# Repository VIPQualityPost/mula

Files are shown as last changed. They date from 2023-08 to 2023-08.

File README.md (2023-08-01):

A small 16ch 100MHz logic analyzer with 2-5V protected inputs that is 
compliant with SUMP/OLS and is usable in sigrok. It is based on 
the rp2040 rust logic analyzer firmware 
[`ula`](https://github.com/dotcypress/ula.git) written by 
[@dotcypress](https://github.com/dotcypress). The 
small form factor is designed for a socket to be designed into a circuit board 
using cheap and widely available m.2 sockets, or by using some custom 
carriers which allow you to use popular flying probes, like the ones 
provided with bitmagic or the classic HP 01652-61608.

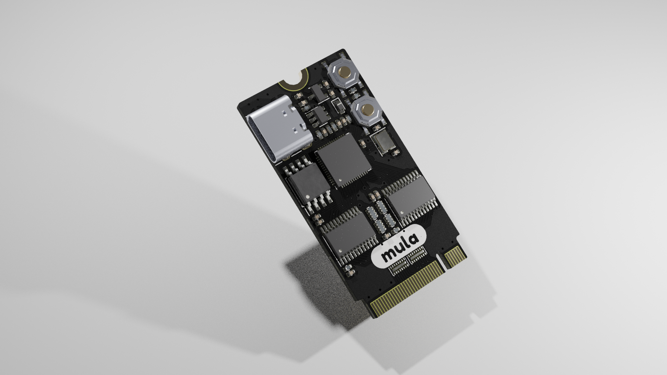
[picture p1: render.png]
3D render of PCB


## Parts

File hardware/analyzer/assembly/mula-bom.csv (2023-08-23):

Comment | Designator | Footprint | JLCPCB Part #
10k | R109,R107,R108,R106 | 0402_R
LED | D101 | 0603_D | C2290
IP4252CZ16-8-TTL,1 | L102,L101 | UDFN-16 | C458218
W25Q128JVS | U101 | SOIC-8 | C97521
12MHz | Y101 | Crystal_SMD_3225 | C9002
SN74LVC4245 | U106,U105 | TSSOP-24 | C7859
XC6206 | U104 | SOT-23 | C5446
SRV05-4 | U103 | SOT-23-6 | C85364
RP2040 | U102 | QFN-56 | C2040
BUTTON | SW101, SW102 | TS-1187A-B-A-B | C318884
150k | RN104,RN103,RN102,RN101 | R_Array_Concave_4x0402 | C425271
27R | R105,R104 | 0402_R
5k1 | R103,R102 | 0402_R
1k | R101 | 0402_R
USB_C_Receptacle_USB2.0 | J101 | HRO_TYPE-C-31-M-12 | C165948
100n | C116,C115,C112,C111,C109,C107,C106,C105 | 0402_C
4u7 | C114,C108 | 0402_C
1u | C113,C110 | 0402_C
47p | C104,C103 | 0402_C
20p | C102,C101 | 0402_C

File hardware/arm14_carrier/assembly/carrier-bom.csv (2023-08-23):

Comment | Designator | Footprint | LCSC Part #
BANKS | J101, J102 | HDR-SMD_14P-P1.27-V-M-R2-C7-LS5.3 | C3975190
NASB0-S6701-TPH4 | CN101 | CONN-SMD_NXSB0-S67XX-XXH4 | C367024

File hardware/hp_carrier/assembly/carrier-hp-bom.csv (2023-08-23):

Comment | Designator | Footprint | LCSC Part #
NASB0-S6701-TPH4 | CN101 | CONN-SMD_NXSB0-S67XX-XXH4 | C367024

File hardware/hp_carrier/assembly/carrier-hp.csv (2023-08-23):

Id | Designator | Footprint | Quantity | Designation | Supplier and ref
1 | J101 | IDC-Header_2x20_P2.54mm_Horizontal | 1 | HP_PROBE
2 | H101,H104,H102,H103 | MountingHole_3mm_Pad | 4 | M3
3 | CN101 | CONN-SMD_NXSB0-S67XX-XXH4 | 1 | NASB0-S6701-TPH4
4 | H105 | MountingHole_2.2mm_M2_DIN965_Pad | 1 | M2

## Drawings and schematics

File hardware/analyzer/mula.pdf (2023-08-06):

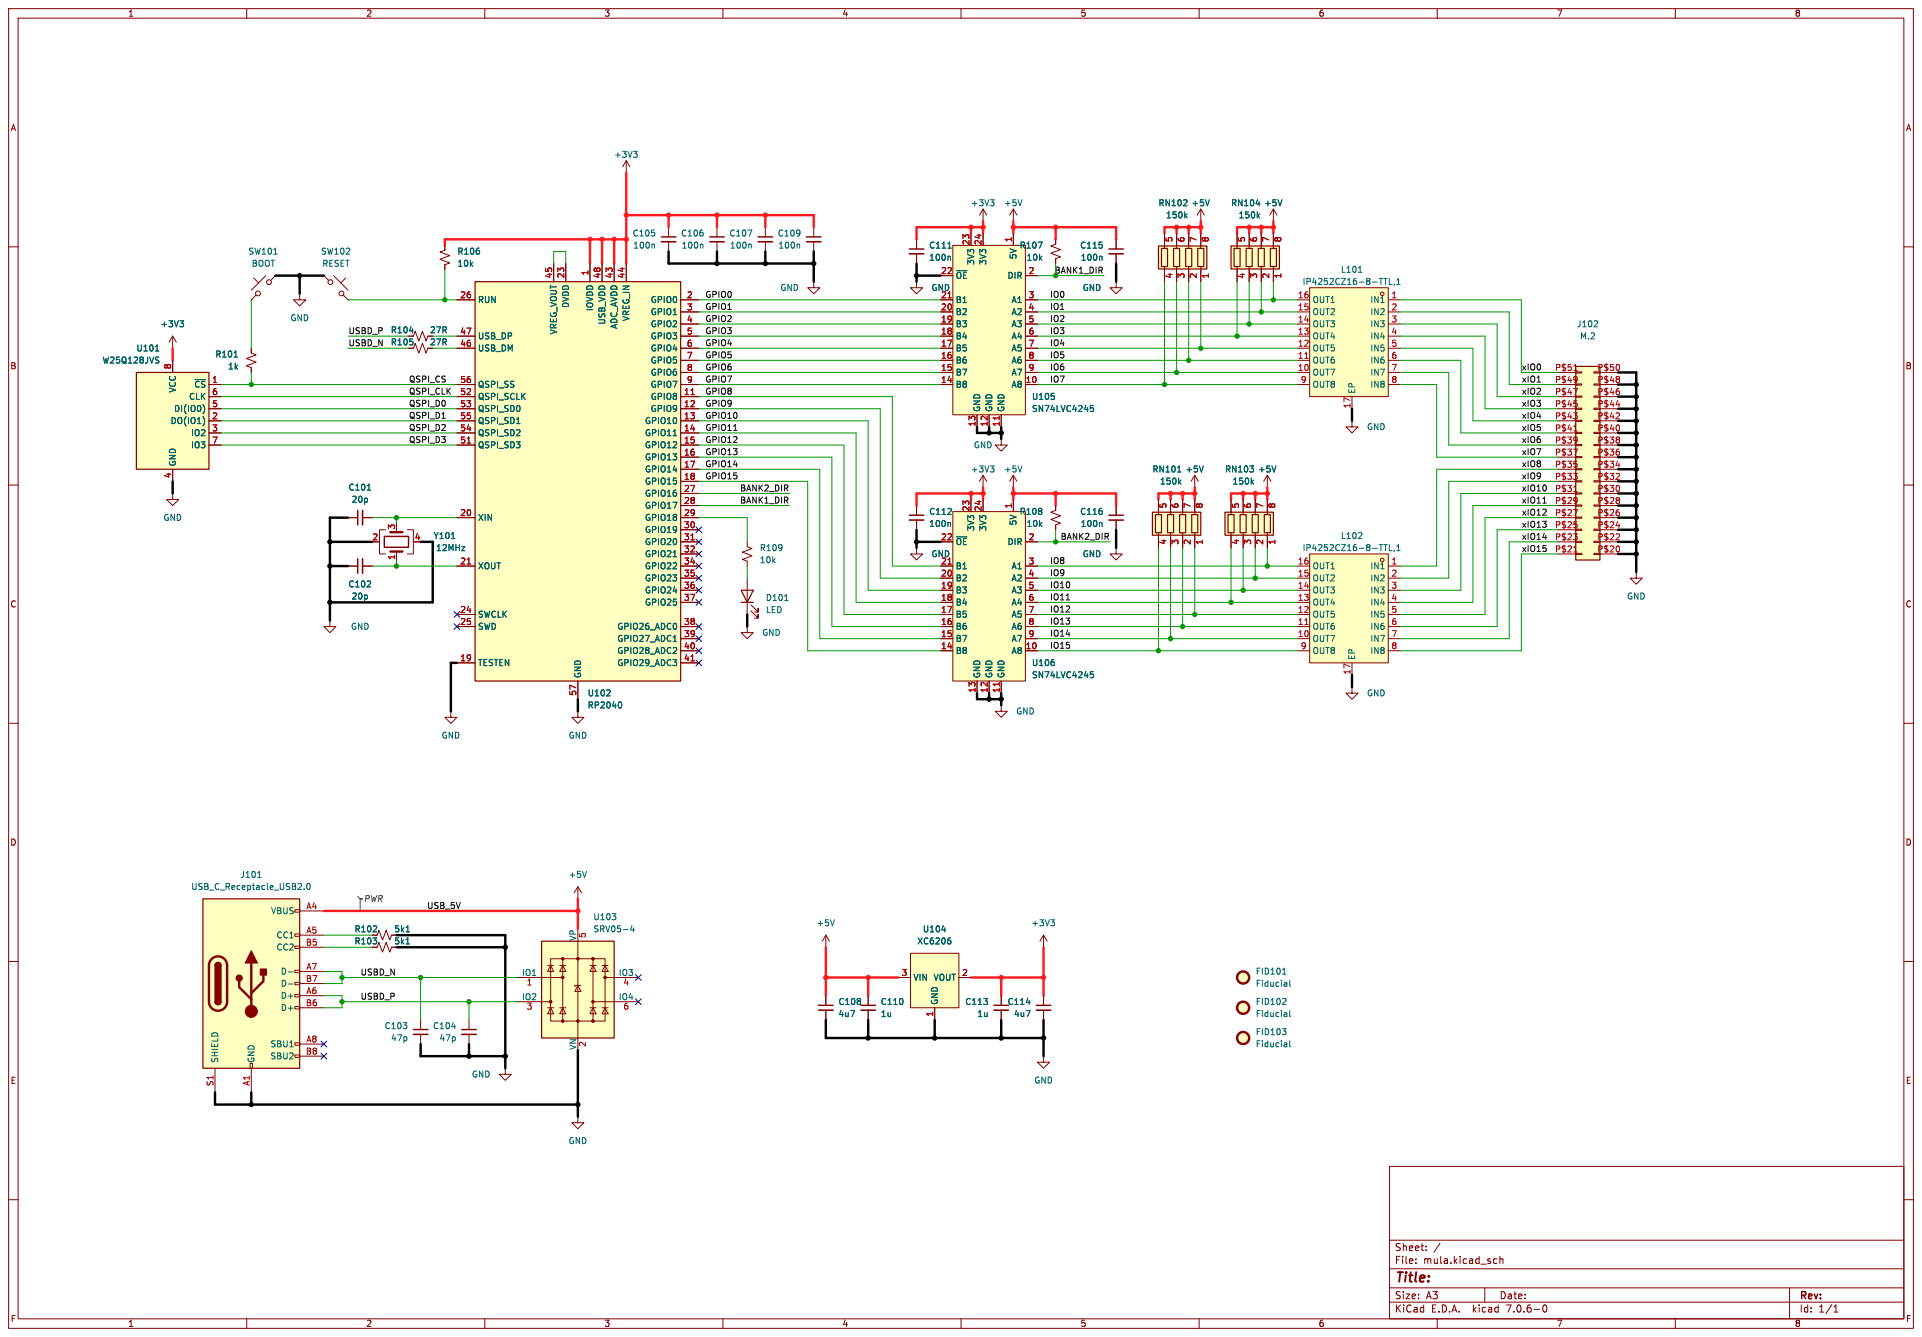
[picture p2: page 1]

1 GPIO8 11 GPIO9 12 GPIO10 13 GPIO11 14 GPIO12 15 GPIO13 16 GPIO14 17 GPIO15 18 TESTEN 19 GPIO0 2 XIN 20 XOUT 21 DVDD 23 SWCLK 24 SWD 25 RUN 26 GPIO16 27 GPIO17 28 GPIO18 29 GPIO1 3 GPIO19 30 GPIO20 31 GPIO21 32 GPIO22 34 GPIO23 35 GPIO24 36 GPIO25 37 GPIO26_ADC0 38 GPIO27_ADC1 39 GPIO2 4 GPIO28_ADC2 40 GPIO29_ADC3 41 ADC_AVDD 43 VREG_IN 44 VREG_VOUT 45 USB_DM 46 USB_DP 47 USB_VDD 48 GPIO3 5 QSPI_SD3 51 QSPI_SCLK 52 QSPI_SD0 53 QSPI_SD2 54 QSPI_SD1 55 QSPI_SS 56 GND 57 GPIO4 6 GPIO5 7 GPIO6 8 GPIO7 9 U102 RP2040 C101

1 GPIO8 11 GPIO9 12 GPIO10 13 GPIO11 14 GPIO12 15 GPIO13 16 GPIO14 17 GPIO15 18 TESTEN 19 GPIO0 2 XIN 20 XOUT 21 DVDD 23 SWCLK 24 SWD 25 RUN 26 GPIO16 27 GPIO17 28 GPIO18 29 GPIO1 3 GPIO19 30 GPIO20 31 GPIO21 32 GPIO22 34 GPIO23 35 GPIO24 36 GPIO25 37 GPIO26_ADC0 38 GPIO27_ADC1 39 GPIO2 4 GPIO28_ADC2 40 GPIO29_ADC3 41 ADC_AVDD 43 VREG_IN 44 VREG_VOUT 45 USB_DM 46 USB_DP 47 USB_VDD 48 GPIO3 5 QSPI_SD3 51 QSPI_SCLK 52 QSPI_SD0 53 QSPI_SD2 54 QSPI_SD1 55 QSPI_SS 56 GND 57 GPIO4 6 GPIO5 7 GPIO6 8 GPIO7 9 Y101

Id: 1/1 Title: File: mula.kicad_sch Sheet: / GND

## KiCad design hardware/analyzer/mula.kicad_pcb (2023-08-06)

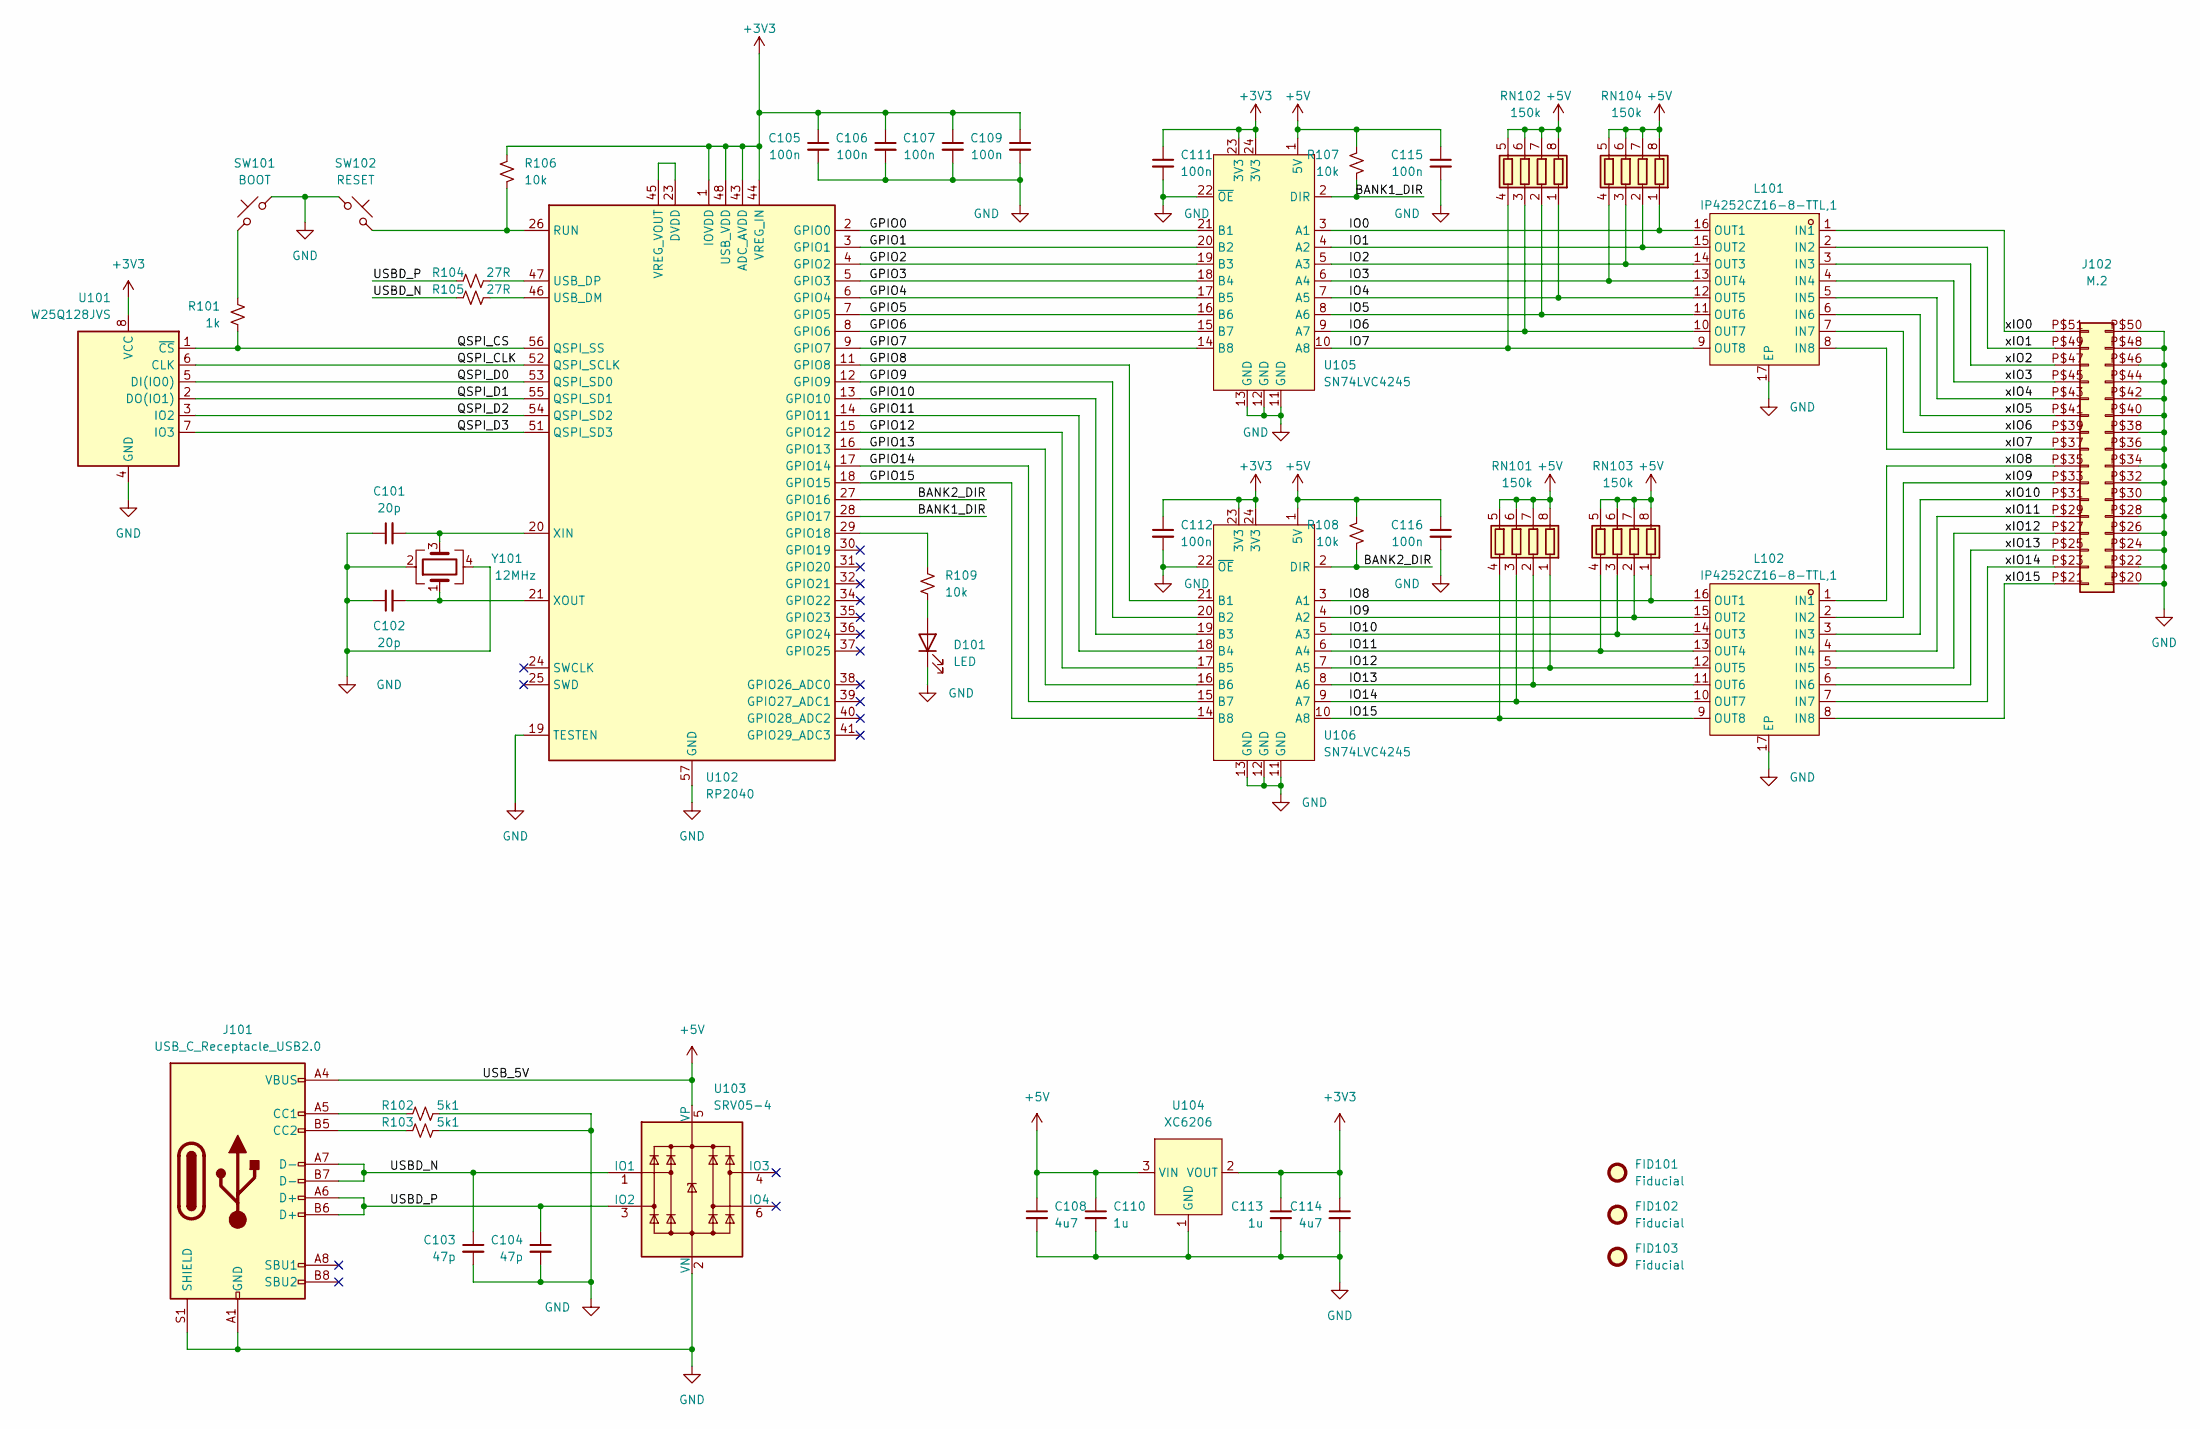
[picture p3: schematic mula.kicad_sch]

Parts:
C101, C102: 20p; C_0402_1005Metric
C103, C104: 47p; C_0402_1005Metric
C105, C106, C107, C109, C111, C112, C115, C116: 100n; C_0402_1005Metric
C108, C114: 4u7; C_0402_1005Metric
C110, C113: 1u; C_0402_1005Metric
D101: LED; D_0603_1608Metric
FID101, FID102, FID103: Fiducial; Fiducial_0.5mm_Mask1mm
J101: USB_C_Receptacle_USB2.0; USB_C_Receptacle_HRO_TYPE-C-31-M-12; LCSC Part C165948
J102: M.2; M.2-B-KEY
L101, L102: IP4252CZ16-8-TTL,1; UDFN-16_L3.3-W1.4-P0.40-BL-EP; LCSC Part C458218
R101: 1k; R_0402_1005Metric
R102, R103: 5k1; R_0402_1005Metric
R104, R105: 27R; R_0402_1005Metric
R106, R107, R108, R109: 10k; R_0402_1005Metric
RN101, RN102, RN103, RN104: 150k; R_Array_Concave_4x0402; LCSC Part C425271
SW101: BOOT; TS-1187A-B-A-B; LCSC Part C318884
SW102: RESET; TS-1187A-B-A-B; LCSC Part C318884
U101: W25Q128JVS; SOIC-8W_5.3x5.3mm_P1.27mm; LCSC Part C97521
U102: RP2040; QFN-56-1EP_7x7mm_P0.4mm_EP3.2x3.2mm; LCSC Part C2040
U103: SRV05-4; SOT-23-6; LCSC Part C85364
U104: XC6206; SOT-23; LCSC Part C5446
U105, U106: SN74LVC4245; TSSOP-24_4.4x7.8mm_P0.65mm; LCSC Part C7859
Y101: 12MHz; Crystal_SMD_3225-4Pin_3.2x2.5mm; LCSC Part C9002

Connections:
+3V3: C105.1, C106.1, C107.1, C109.1, C111.1, C112.1, C113.1, C114.1, R106.1, U101.8 (VCC), U102.1 (IOVDD), U102.10 (IOVDD), U102.22 (IOVDD), U102.33 (IOVDD), U102.42 (IOVDD), U102.43 (ADC_AVDD), U102.44 (VREG_IN), U102.48 (USB_VDD), U102.49 (IOVDD), U104.2 (VOUT), U105.23 (3V3), U105.24 (3V3), U106.23 (3V3), U106.24 (3V3)
+5V: C108.1, C110.1, C115.1, C116.1, J101.A4 (VBUS), J101.A9 (VBUS), J101.B4 (VBUS), J101.B9 (VBUS), R107.1, R108.1, RN101.5 (R4.2), RN101.6 (R3.2), RN101.7 (R2.2), RN101.8 (R1.2), RN102.5 (R4.2), RN102.6 (R3.2), RN102.7 (R2.2), RN102.8 (R1.2), RN103.5 (R4.2), RN103.6 (R3.2), RN103.7 (R2.2), RN103.8 (R1.2), RN104.5 (R4.2), RN104.6 (R3.2), RN104.7 (R2.2), RN104.8 (R1.2), U103.5 (VP), U104.3 (VIN), U105.1 (5V), U106.1 (5V)
/BANK1_DIR: R107.2, U102.28 (GPIO17), U105.2 (DIR)
/BANK2_DIR: R108.2, U102.27 (GPIO16), U106.2 (DIR)
/GPIO0: U102.2 (GPIO0), U105.21 (B1)
/GPIO1: U102.3 (GPIO1), U105.20 (B2)
/GPIO2: U102.4 (GPIO2), U105.19 (B3)
/GPIO3: U102.5 (GPIO3), U105.18 (B4)
/GPIO4: U102.6 (GPIO4), U105.17 (B5)
/GPIO5: U102.7 (GPIO5), U105.16 (B6)
/GPIO6: U102.8 (GPIO6), U105.15 (B7)
/GPIO7: U102.9 (GPIO7), U105.14 (B8)
/GPIO8: U102.11 (GPIO8), U106.21 (B1)
/GPIO9: U102.12 (GPIO9), U106.20 (B2)
/GPIO10: U102.13 (GPIO10), U106.19 (B3)
/GPIO11: U102.14 (GPIO11), U106.18 (B4)
/GPIO12: U102.15 (GPIO12), U106.17 (B5)
/GPIO13: U102.16 (GPIO13), U106.16 (B6)
/GPIO14: U102.17 (GPIO14), U106.15 (B7)
/GPIO15: U102.18 (GPIO15), U106.14 (B8)
/IO0: L101.16 (OUT1), RN104.1 (R1.1), U105.3 (A1)
/IO1: L101.15 (OUT2), RN104.2 (R2.1), U105.4 (A2)
/IO2: L101.14 (OUT3), RN104.3 (R3.1), U105.5 (A3)
/IO3: L101.13 (OUT4), RN104.4 (R4.1), U105.6 (A4)
/IO4: L101.12 (OUT5), RN102.1 (R1.1), U105.7 (A5)
/IO5: L101.11 (OUT6), RN102.2 (R2.1), U105.8 (A6)
/IO6: L101.10 (OUT7), RN102.3 (R3.1), U105.9 (A7)
/IO7: L101.9 (OUT8), RN102.4 (R4.1), U105.10 (A8)
/IO8: L102.16 (OUT1), RN103.1 (R1.1), U106.3 (A1)
/IO9: L102.15 (OUT2), RN103.2 (R2.1), U106.4 (A2)
/IO10: L102.14 (OUT3), RN103.3 (R3.1), U106.5 (A3)
/IO11: L102.13 (OUT4), RN103.4 (R4.1), U106.6 (A4)
/IO12: L102.12 (OUT5), RN101.1 (R1.1), U106.7 (A5)
/IO13: L102.11 (OUT6), RN101.2 (R2.1), U106.8 (A6)
/IO14: L102.10 (OUT7), RN101.3 (R3.1), U106.9 (A7)
/IO15: L102.9 (OUT8), RN101.4 (R4.1), U106.10 (A8)
/QSPI_CLK: U101.6 (CLK), U102.52 (QSPI_SCLK)
/QSPI_CS: R101.2, U101.1 (~CS), U102.56 (QSPI_SS)
/QSPI_D0: U101.5 (DI(IO0)), U102.53 (QSPI_SD0)
/QSPI_D1: U101.2 (DO(IO1)), U102.55 (QSPI_SD1)
/QSPI_D2: U101.3 (IO2), U102.54 (QSPI_SD2)
/QSPI_D3: U101.7 (IO3), U102.51 (QSPI_SD3)
/USBD_N: C103.1, J101.A7 (D-), J101.B7 (D-), R105.1, U103.1 (IO1)
/USBD_P: C104.1, J101.A6 (D+), J101.B6 (D+), R104.1, U103.3 (IO2)
/xIO0: J102.P$51 (Pin_32), L101.1 (IN1)
/xIO1: J102.P$49 (Pin_31), L101.2 (IN2)
/xIO2: J102.P$47 (Pin_30), L101.3 (IN3)
/xIO3: J102.P$45 (Pin_29), L101.4 (IN4)
/xIO4: J102.P$43 (Pin_28), L101.5 (IN5)
/xIO5: J102.P$41 (Pin_27), L101.6 (IN6)
/xIO6: J102.P$39 (Pin_26), L101.7 (IN7)
/xIO7: J102.P$37 (Pin_25), L101.8 (IN8)
/xIO8: J102.P$35 (Pin_24), L102.1 (IN1)
/xIO9: J102.P$33 (Pin_23), L102.2 (IN2)
/xIO10: J102.P$31 (Pin_22), L102.3 (IN3)
/xIO11: J102.P$29 (Pin_21), L102.4 (IN4)
/xIO12: J102.P$27 (Pin_20), L102.5 (IN5)
/xIO13: J102.P$25 (Pin_19), L102.6 (IN6)
/xIO14: J102.P$23 (Pin_18), L102.7 (IN7)
/xIO15: J102.P$21 (Pin_17), L102.8 (IN8)
GND: C101.1, C102.1, C103.2, C104.2, C105.2, C106.2, C107.2, C108.2, C109.2, C110.2, C111.2, C112.2, C113.2, C114.2, C115.2, C116.2, D101.1 (K), J101.A1 (GND), J101.A12 (GND), J101.B1 (GND), J101.B12 (GND), J101.S1 (SHIELD), J102.P$20 (Pin_1), J102.P$22 (Pin_2), J102.P$24 (Pin_3), J102.P$26 (Pin_4), J102.P$28 (Pin_5), J102.P$30 (Pin_6), J102.P$32 (Pin_7), J102.P$34 (Pin_8), J102.P$36 (Pin_9), J102.P$38 (Pin_10), J102.P$40 (Pin_11), J102.P$42 (Pin_12), J102.P$44 (Pin_13), J102.P$46 (Pin_14), J102.P$48 (Pin_15), J102.P$50 (Pin_16), L101.17 (EP), L102.17 (EP), R102.2, R103.2, SW101.1, SW102.1, U101.4 (GND), U102.19 (TESTEN), U102.57 (GND), U103.2 (VN), U104.1 (GND), U105.11 (GND), U105.12 (GND), U105.13 (GND), U105.22 (~OE), U106.11 (GND), U106.12 (GND), U106.13 (GND), U106.22 (~OE), Y101.2, Y101.4
unnamed: D101.2 (A), R109.2
unnamed: J101.A5 (CC1), R102.1
unnamed: J101.B5 (CC2), R103.1
unnamed: R101.1, SW101.2
unnamed: R109.1, U102.29 (GPIO18)
unnamed: R106.2, SW102.2, U102.26 (RUN)
unnamed: R105.2, U102.46 (USB_DM)
unnamed: R104.2, U102.47 (USB_DP)
unnamed: U102.23 (DVDD), U102.45 (VREG_VOUT), U102.50 (DVDD)
unnamed: C101.2, U102.20 (XIN), Y101.3
unnamed: C102.2, U102.21 (XOUT), Y101.1

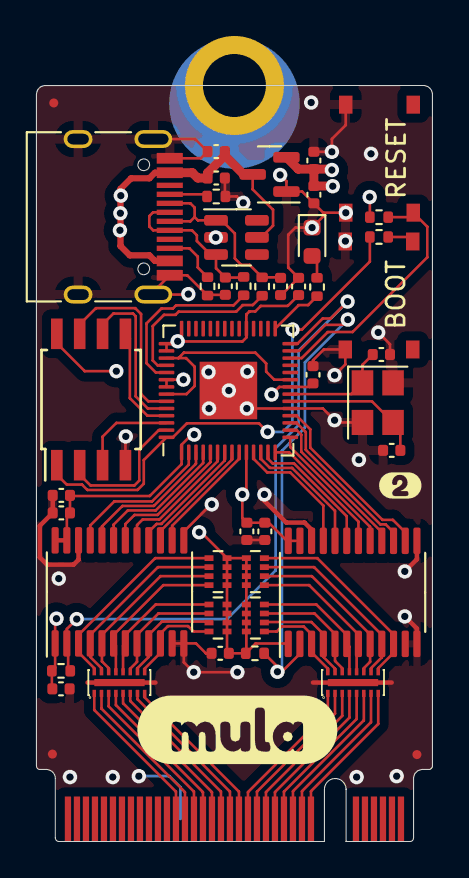
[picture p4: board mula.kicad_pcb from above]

Board: 4 copper layers, 22.0 x 42.0 mm, 48 parts (0 on the bottom side), 72 nets.

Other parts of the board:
kibuzzard-64C5EFF0: G***; kibuzzard-64C5EFF0
kibuzzard-64C8408B: G***; kibuzzard-64C8408B

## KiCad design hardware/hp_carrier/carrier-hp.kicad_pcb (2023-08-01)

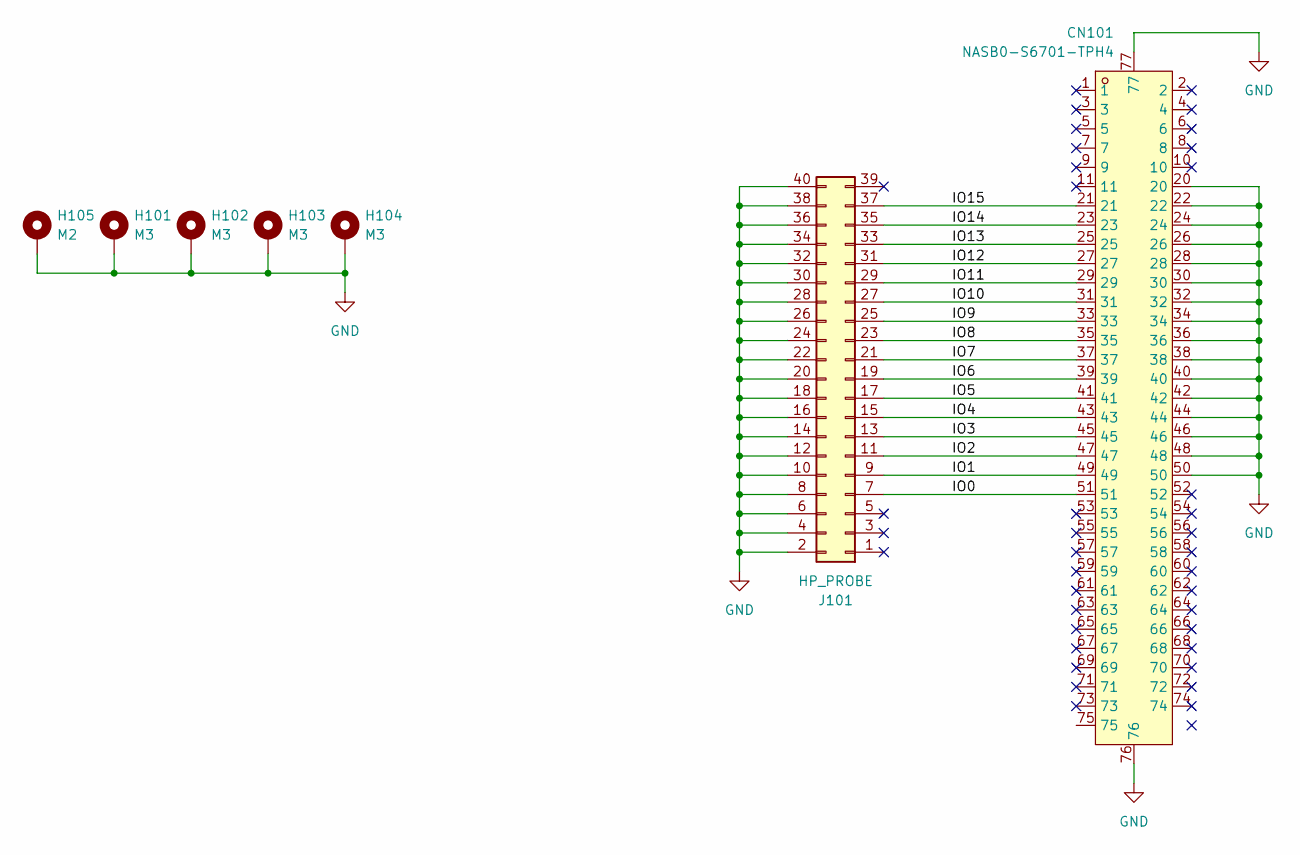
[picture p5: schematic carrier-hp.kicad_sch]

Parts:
CN101: NASB0-S6701-TPH4; CONN-SMD_NXSB0-S67XX-XXH4; LCSC Part C367030
H101, H102, H103, H104: M3; MountingHole_3mm_Pad
H105: M2; MountingHole_2.2mm_M2_DIN965_Pad
J101: HP_PROBE; IDC-Header_2x20_P2.54mm_Latch_Horizontal

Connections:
/IO0: CN101.51, J101.7
/IO1: CN101.49, J101.9
/IO2: CN101.47, J101.11
/IO3: CN101.45, J101.13
/IO4: CN101.43, J101.15
/IO5: CN101.41, J101.17
/IO6: CN101.39, J101.19
/IO7: CN101.37, J101.21
/IO8: CN101.35, J101.23
/IO9: CN101.33, J101.25
/IO10: CN101.31, J101.27
/IO11: CN101.29, J101.29
/IO12: CN101.27, J101.31
/IO13: CN101.25, J101.33
/IO14: CN101.23, J101.35
/IO15: CN101.21, J101.37
GND: CN101.20, CN101.22, CN101.24, CN101.26, CN101.28, CN101.30, CN101.32, CN101.34, CN101.36, CN101.38, CN101.40, CN101.42, CN101.44, CN101.46, CN101.48, CN101.50, CN101.76, CN101.77, H101.1, H102.1, H103.1, H104.1, H105.1, J101.2, J101.4, J101.6, J101.8, J101.10, J101.12, J101.14, J101.16, J101.18, J101.20, J101.22, J101.24, J101.26, J101.28, J101.30, J101.32, J101.34, J101.36, J101.38, J101.40

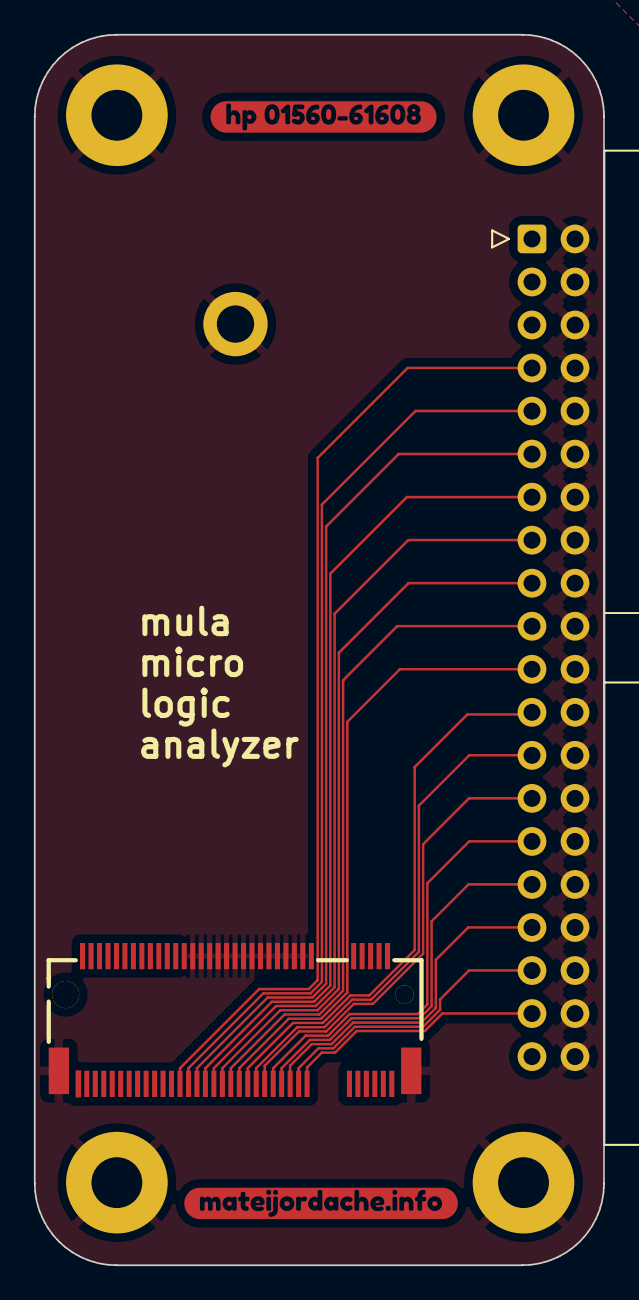
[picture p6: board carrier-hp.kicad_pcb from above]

Board: 4 copper layers, 33.6 x 72.6 mm, 9 parts (0 on the bottom side), 17 nets.

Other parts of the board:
kibuzzard-64C862C8: G***; kibuzzard-64C862C8
kibuzzard-64C85072: G***; kibuzzard-64C85072

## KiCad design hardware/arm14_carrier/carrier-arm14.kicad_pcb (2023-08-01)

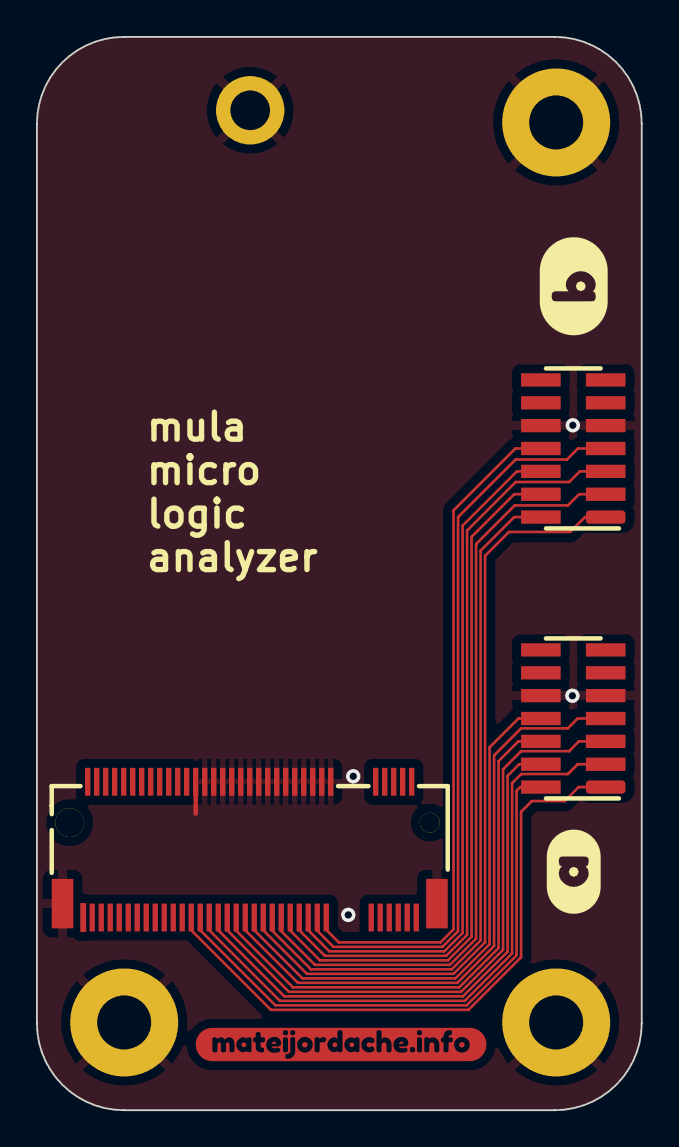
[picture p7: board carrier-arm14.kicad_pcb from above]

Board: 4 copper layers, 33.6 x 59.6 mm, 10 parts (0 on the bottom side), 17 nets.

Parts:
CN101: NASB0-S6701-TPH4; CONN-SMD_NXSB0-S67XX-XXH4
H102, H103, H104: M3; MountingHole_3mm_Pad
H105: M2; MountingHole_2.2mm_M2_DIN965_Pad
J101: BANK_A; HDR-SMD_14P-P1.27-V-M-R2-C7-LS5.3
J102: BANK_B; HDR-SMD_14P-P1.27-V-M-R2-C7-LS5.3
kibuzzard-64C6FCDD: G***; kibuzzard-64C6FCDD
kibuzzard-64C70043: G***; kibuzzard-64C70043
kibuzzard-64C85072: G***; kibuzzard-64C85072

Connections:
/IO0: CN101.51, J101.1
/IO1: CN101.49, J101.2
/IO2: CN101.47, J101.3
/IO3: CN101.45, J101.4
/IO4: CN101.43, J101.5
/IO5: CN101.41, J101.6
/IO6: CN101.39, J101.7
/IO7: CN101.37, J101.8
/IO8: CN101.35, J102.1
/IO9: CN101.33, J102.2
/IO10: CN101.31, J102.3
/IO11: CN101.29, J102.4
/IO12: CN101.27, J102.5
/IO13: CN101.25, J102.6
/IO14: CN101.23, J102.7
/IO15: CN101.21, J102.8
GND: CN101.20, CN101.22, CN101.24, CN101.26, CN101.28, CN101.30, CN101.32, CN101.34, CN101.36, CN101.38, CN101.40, CN101.42, CN101.44, CN101.46, CN101.48, CN101.50, CN101.76, CN101.77, H102.1, H103.1, H104.1, H105.1, J101.9, J101.10, J102.9, J102.10

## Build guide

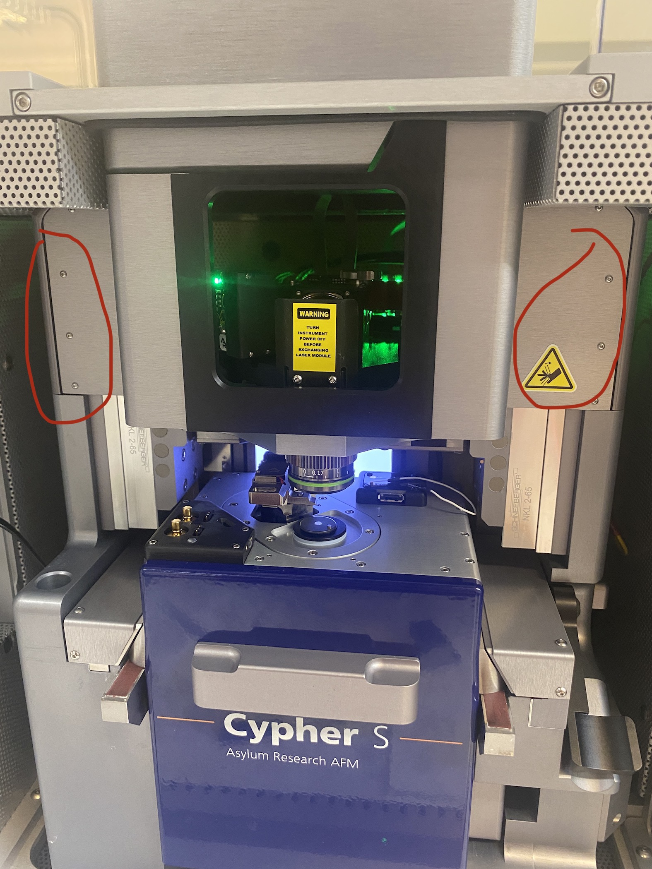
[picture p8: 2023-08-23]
hardware/hp_carrier/assembly/IMG_0446.jpeg

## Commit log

2023-08-01 init commit
    [carrier-arm14.kicad_pcb, carrier-arm14.kicad_sch, carrier-hp.kicad_pcb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]
2023-08-06 move things around
    [mula.kicad_pcb, mula.kicad_sch]
2023-08-23 add in assembly files
    [carrier-arm14-B_Cu.gbr, carrier-arm14-B_Mask.gbr, carrier-arm14-B_Paste.gbr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]
2023-08-23 remove extra cpl pos file
    [mula-all-pos.csv]
